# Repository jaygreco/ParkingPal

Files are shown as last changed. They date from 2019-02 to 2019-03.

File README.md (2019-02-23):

# ParkingPal
An open-source distance meter for easy garage parking. See [the thingiverse page](https://www.thingiverse.com/thing:3448336) for more info.

## How to use
Compile for the Arduino Pro Micro and upload. By default, the firmware is built for 8 LEDs (the NeoPixel Stick), and will poll the sensor at 3Hz until the read distance has been stable for roughly 10 seconds.

Single-pressing the button will change the operating mode. Double-clicking will cycle the brightness, and long-pressing will set the default parking distance. To set the default parking distance properly, park the car at the normal parking distance, and then long-press the button while making sure to stay clear of the ultrasonic sensor. Once set, the buzzer will beep once.

There are some configuration options in `config.h`. They should be pretty self-explanatory. There really isn't much need to change these unless you want to tweak some specific behavior. 

## Parts list
There's a more detailed BOM [here](https://github.com/jaygreco/ParkingPal/blob/master/PCB/0.1/MCU/MCU_BOM.xlsx).
### Required
| Qty | Part | Link |
|-----|---|---|
| 1 | Arduino Pro Micro | [SparkFun](https://www.sparkfun.com/products/12640) |
| 1 | NeoPixel Stick | [SparkFun](https://www.sparkfun.com/products/12661) |
| 1 | HC-SR04 Sensor | [SparkFun](https://www.sparkfun.com/products/13959) |
| 1 | SMT Pushbutton | [SparkFun](https://www.sparkfun.com/products/8720) |
| 1 | USB A Connector | [Digikey](https://www.digikey.com/products/en?keywords=380-1412-ND) |
| 1 | PCB - MCU | [OSHPark](https://oshpark.com/shared_projects/L5AVMKPm) |
| 1 | PCB - SMU | [OSHPark](https://oshpark.com/shared_projects/UerOD9Ji) |

### Optional (to include buzzer)
| Qty | Part | Link |
|-----|---|---|
| 1 | 12mm Buzzer | [SparkFun](https://www.sparkfun.com/products/7950) |
| 1 | 10k Resistor | [Digikey](https://www.digikey.com/products/en?keywords=RMCF0201FT10K0CT-ND) |
| 1 | 2N7002 N-Ch Fet | [Digikey](https://www.digikey.com/products/en?keywords=2N7002-TPMSCT-ND) |

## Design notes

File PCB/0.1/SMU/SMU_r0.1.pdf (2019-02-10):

USBPCB | USBPCB

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
J2 VCC

TRIG

ECHO USB | GND | USBSensor | USB

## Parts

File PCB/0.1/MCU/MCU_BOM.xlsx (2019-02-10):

Qty | Value | Part | Distributor | Package | Parts | Description
1 | 10k | RMCF0201FT10K0CT-ND | Digikey | 0603 | R1 | 0603 Resistor
1 | BUZZER-PTH_KIT | COM-07950 | Sparkfun | BUZZER-12MM-KIT | LS1 | 12mm Buzzer
1 | MOSFET-NCH-2N7002 | 2N7002-TPMSCT-ND | Digikey | SOT23-3 | Q1 | N-channel MOSFET
1 | SPARKFUN_PRO_MICRO_5V | DEV-12640 | Sparkfun | SPARKFUN_PRO_MICRO | B1 | SparkFun Pro Micro
1 | SWITCH-MOMENTARY-2SMD-REDUNDANT | COM-08720 | Sparkfun | TACTILE-SWITCH-SMD | S1 | NO SMT Button
1 | USB_A | 380-1412-ND | Digikey | USB-A-H | J1 | USB-A Connector

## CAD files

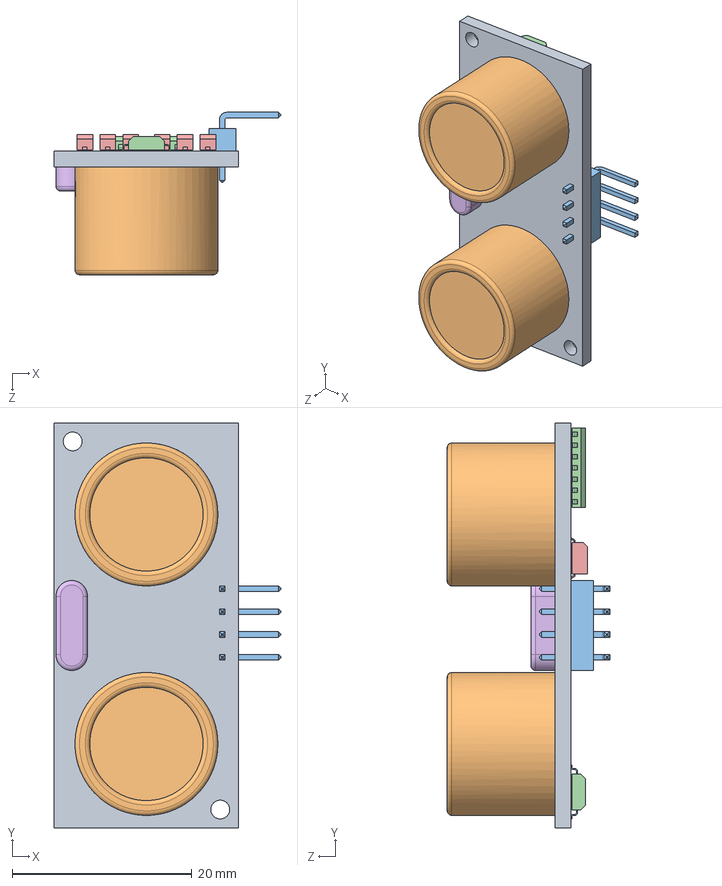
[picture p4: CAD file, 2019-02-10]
CAD/HC-SR04/HC-SR04 Ping Sensor.SLDASM
25.2 x 45.0 x 18.1 mm
PCB
Transducer x 2
3 Pin Header 90 Degree
14 Pin SMT x 3
Cap1 SMT x 6
HC-SR04 Crystal.SLDASM

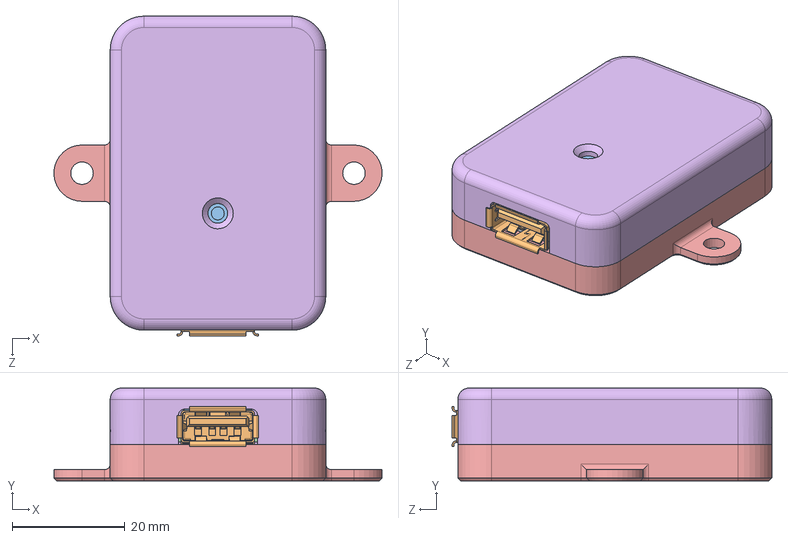
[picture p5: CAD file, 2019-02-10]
CAD/MCU_assem.SLDASM
58.2 x 16.5 x 56.8 mm
MCU_pcb
USB-A
Buzzer
ARDUINO PRO MICRO
Case_bottom
Case_top

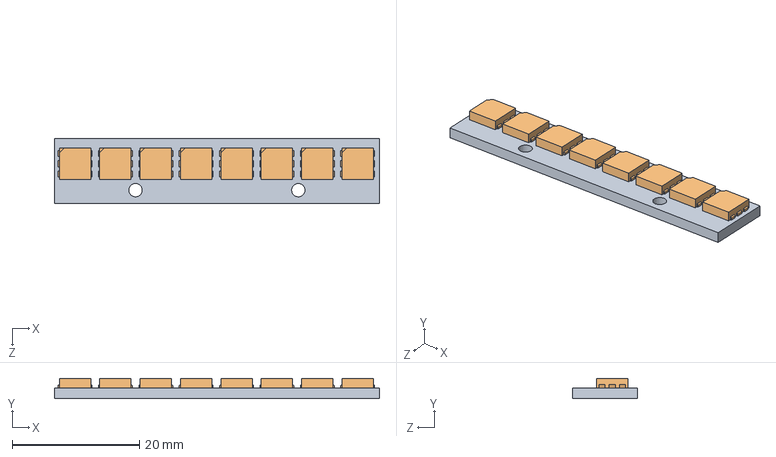
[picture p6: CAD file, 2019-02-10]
CAD/Neopixel Stick/NeoPixel Stick - 8 x WS2812 5050 RGB LED.SLDASM
51.1 x 3.19 x 10.2 mm
NeoPixel Stick - 8 x WS2812 5050 RGB LED
LED - SMD RGB (WS2812) x 8

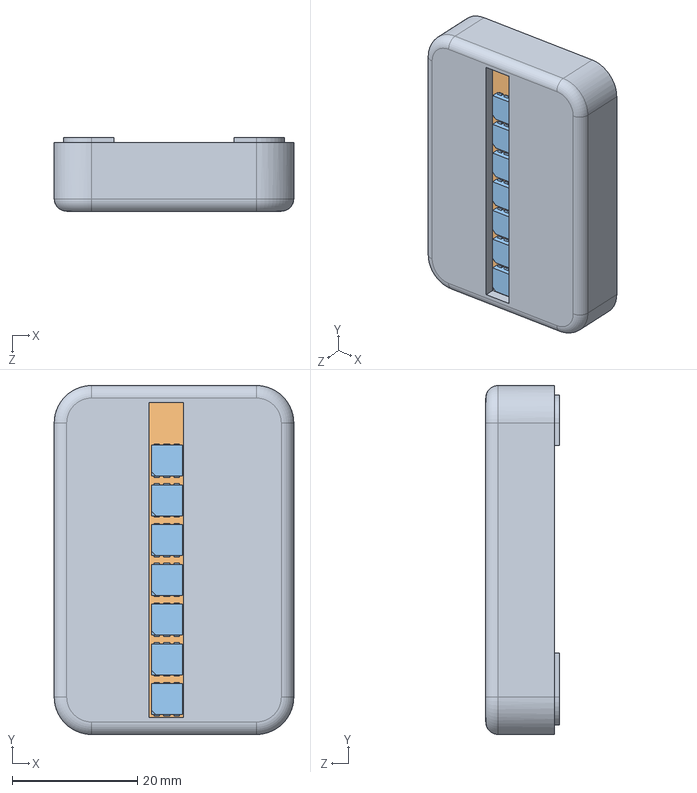
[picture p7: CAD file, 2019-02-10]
CAD/Neopixel Stick/Assem1.SLDASM
38.3 x 55.8 x 11.8 mm
Case_top
NeoPixel Stick - 8 x WS2812 5050 RGB LED
LED - SMD RGB (WS2812) x 7

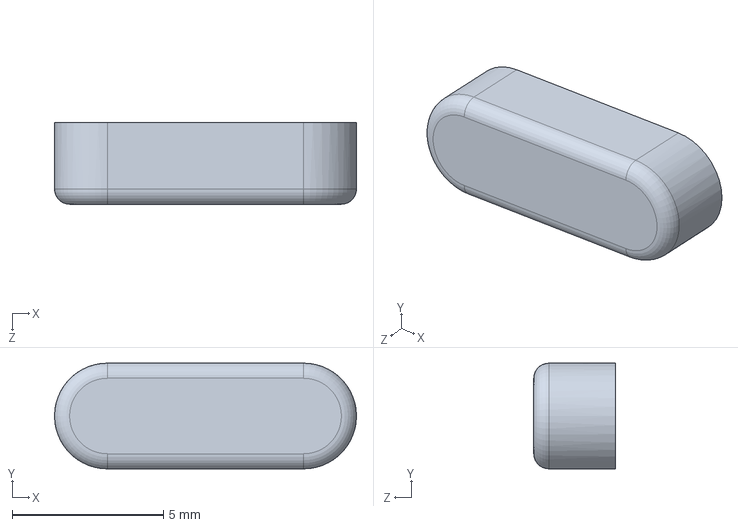
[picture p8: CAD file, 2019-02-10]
CAD/HC-SR04/HC-SR04 Crystal.SLDASM.SLDPRT
10.0 x 3.50 x 2.70 mm

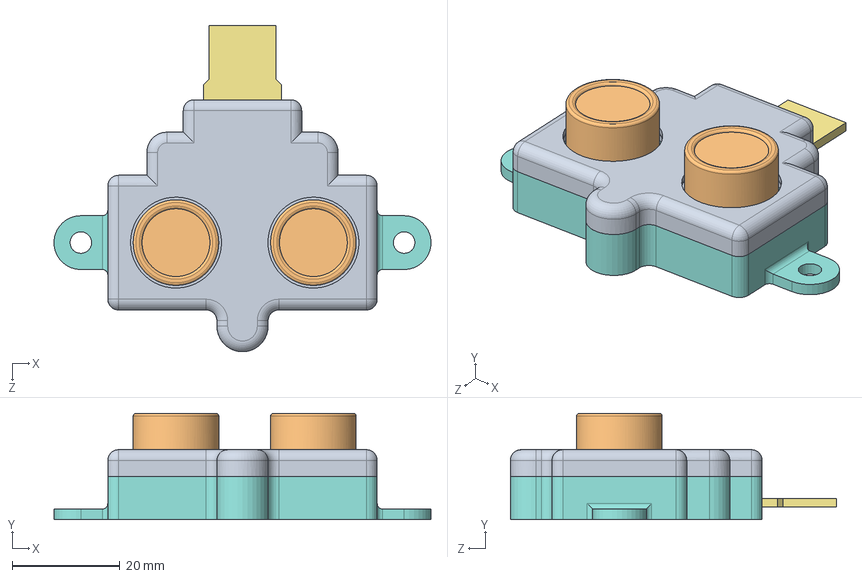
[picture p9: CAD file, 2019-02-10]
CAD/SMU_assem.SLDASM
70.0 x 19.8 x 60.6 mm
PCB
Transducer x 2
3 Pin Header 90 Degree
14 Pin SMT x 3
Cap1 SMT x 6
HC-SR04 Crystal.SLDASM
SMU_pcb
SMU_case_bottom
SMU_case_top

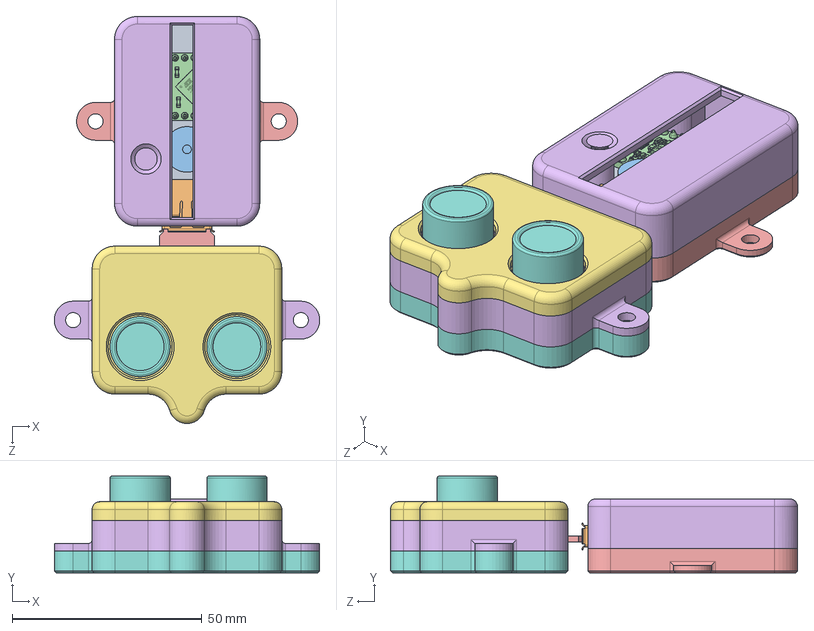
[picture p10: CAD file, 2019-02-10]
CAD/ParkingPal.SLDASM
70.0 x 25.5 x 107.3 mm
MCU_pcb
USB-A
Buzzer
ARDUINO PRO MICRO
Case_bottom
Case_top
PCB
Transducer x 2
3 Pin Header 90 Degree
14 Pin SMT x 3
Cap1 SMT x 6
HC-SR04 Crystal.SLDASM
SMU_pcb
SMU_case_bottom
SMU_case_top
SMU_spacer

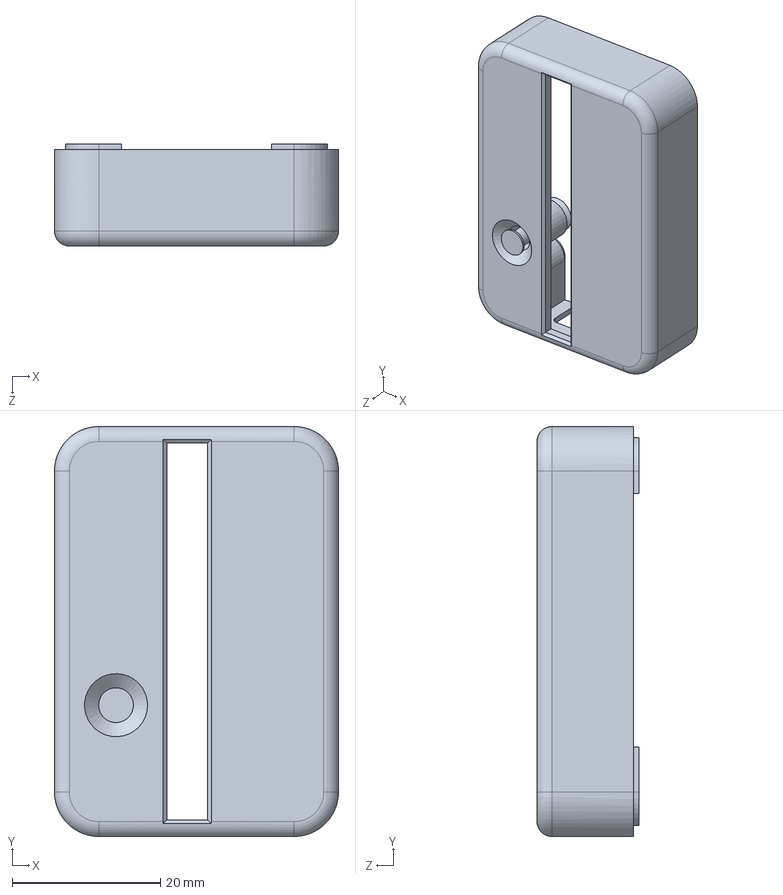
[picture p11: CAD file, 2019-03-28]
CAD/Case_top.SLDPRT
38.3 x 55.3 x 13.8 mm

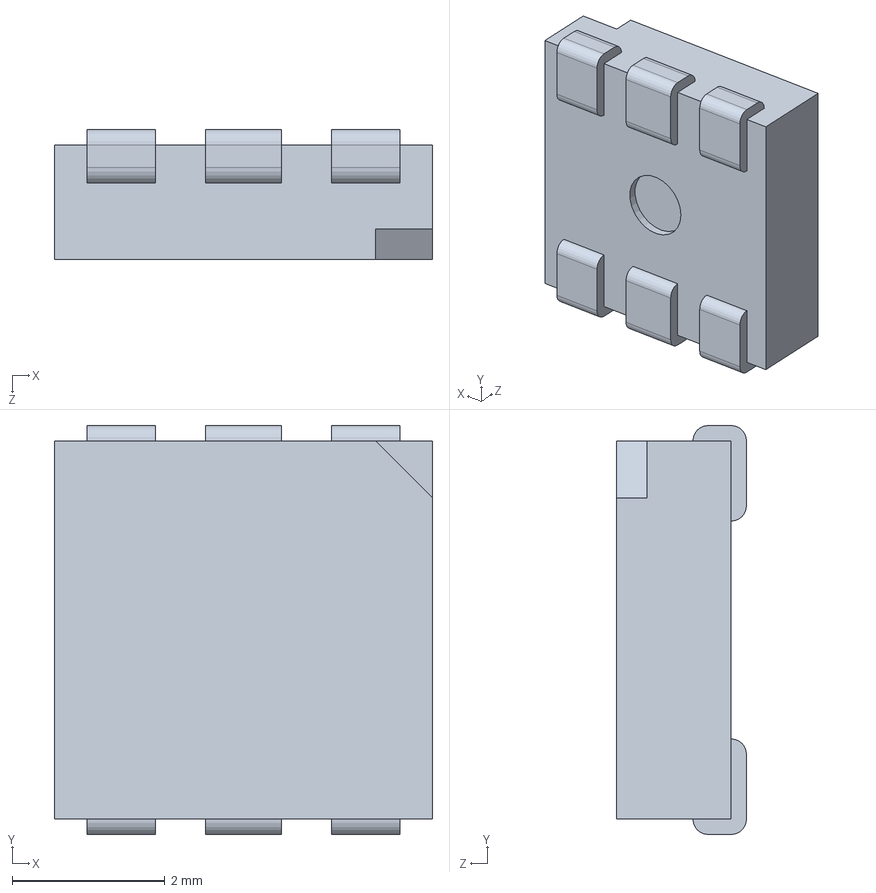
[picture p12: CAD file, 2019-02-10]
CAD/Neopixel Stick/LED - SMD RGB (WS2812).sldprt
4.95 x 5.35 x 1.70 mm

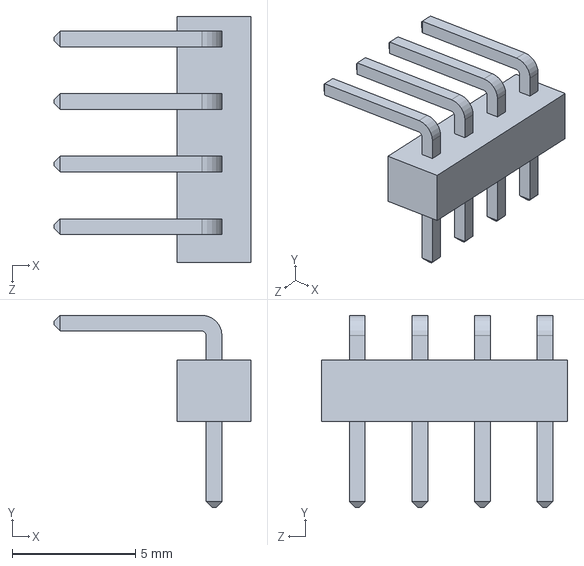
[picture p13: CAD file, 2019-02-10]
CAD/HC-SR04/3 Pin Header 90 Degree.SLDPRT
8.00 x 7.82 x 10.0 mm

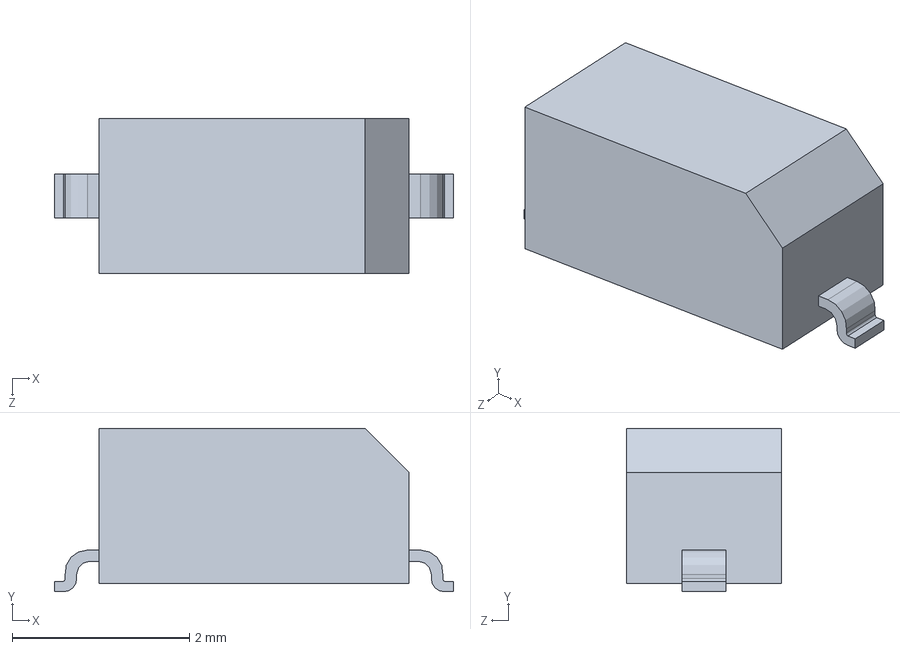
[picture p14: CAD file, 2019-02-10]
CAD/HC-SR04/Cap1 SMT.SLDPRT
4.50 x 1.84 x 1.75 mm

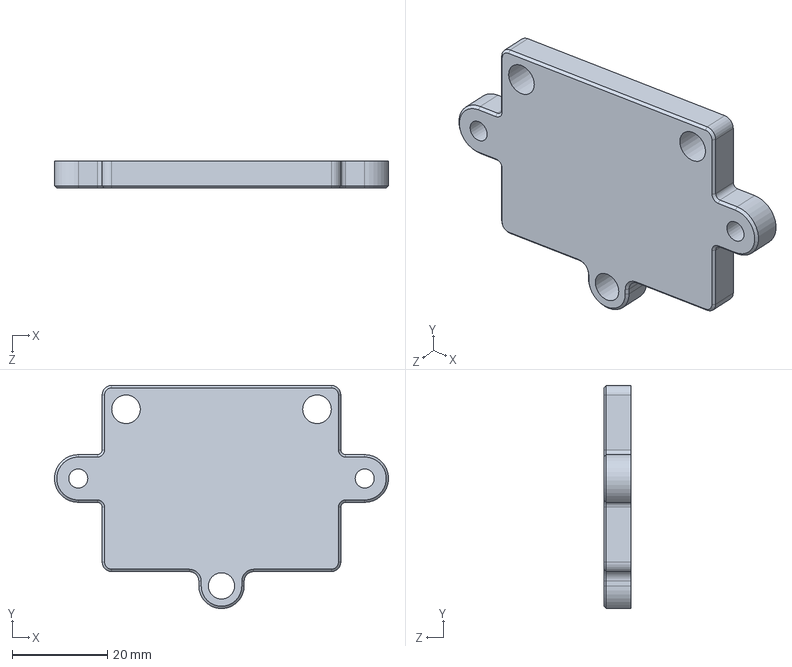
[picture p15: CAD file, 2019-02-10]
CAD/SMU_spacer.SLDPRT
70.0 x 46.8 x 5.75 mm

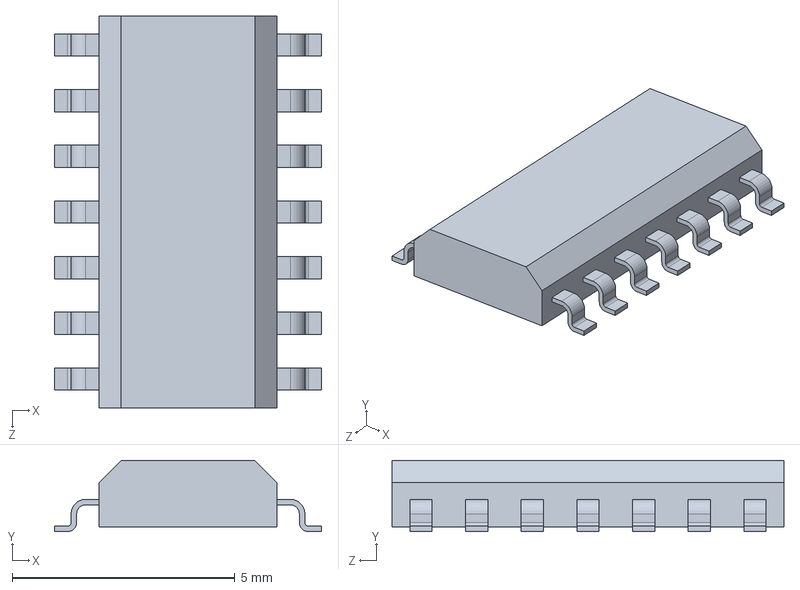
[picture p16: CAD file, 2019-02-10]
CAD/HC-SR04/14 Pin SMT.SLDPRT
6.00 x 1.60 x 8.80 mm

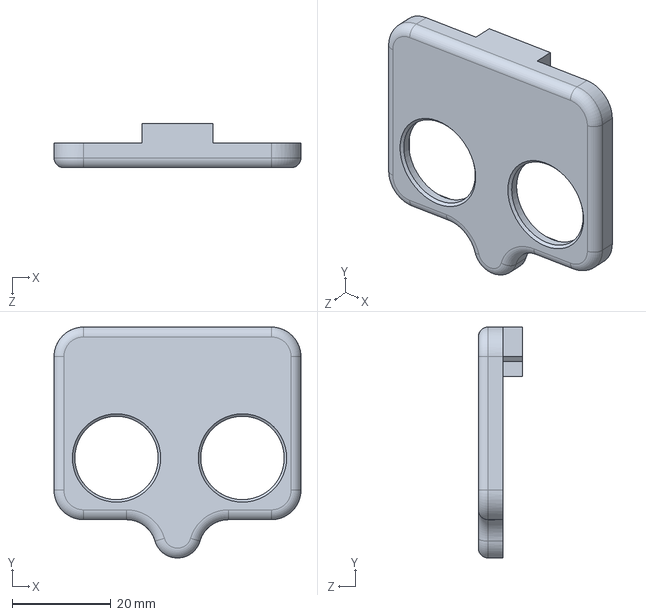
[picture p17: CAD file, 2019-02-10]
CAD/SMU_case_top.SLDPRT
50.0 x 46.7 x 9.00 mm

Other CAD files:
CAD/SMU_pcb.SLDPRT
CAD/HC-SR04/Transducer.SLDPRT
CAD/USB-A.SLDPRT
CAD/HC-SR04/PCB.SLDPRT
CAD/Buzzer.SLDPRT
CAD/Case_bottom.SLDPRT
CAD/MCU_pcb.SLDPRT
CAD/Neopixel Stick/NeoPixel Stick - 8 x WS2812 5050 RGB LED.SLDPRT
CAD/SMU_case_bottom.SLDPRT
CAD/hcSTP.SLDPRT

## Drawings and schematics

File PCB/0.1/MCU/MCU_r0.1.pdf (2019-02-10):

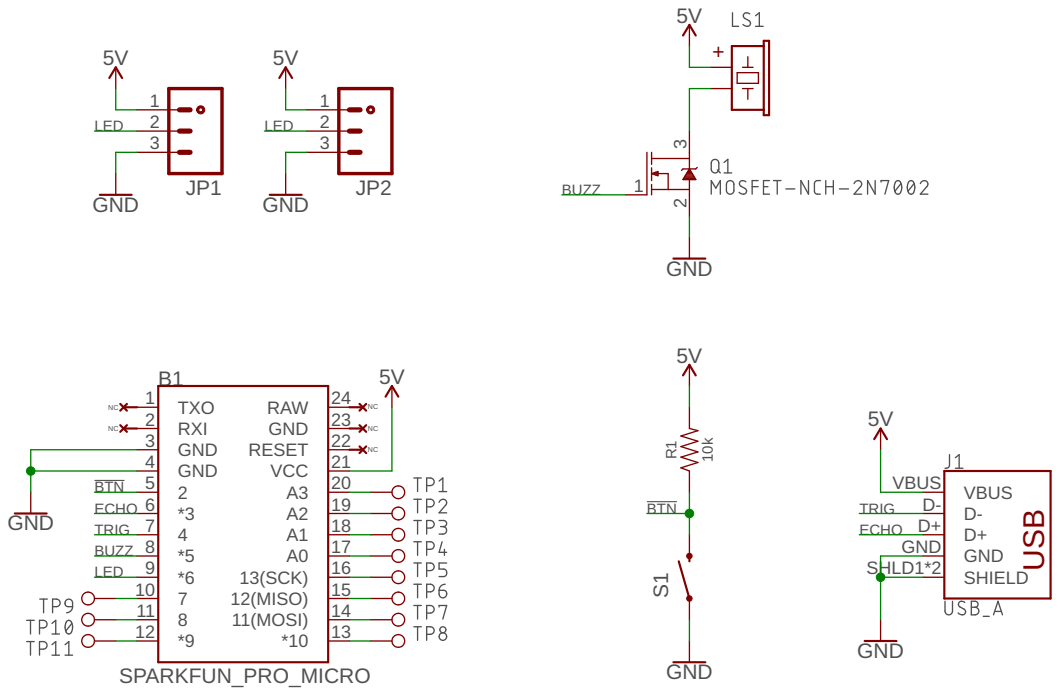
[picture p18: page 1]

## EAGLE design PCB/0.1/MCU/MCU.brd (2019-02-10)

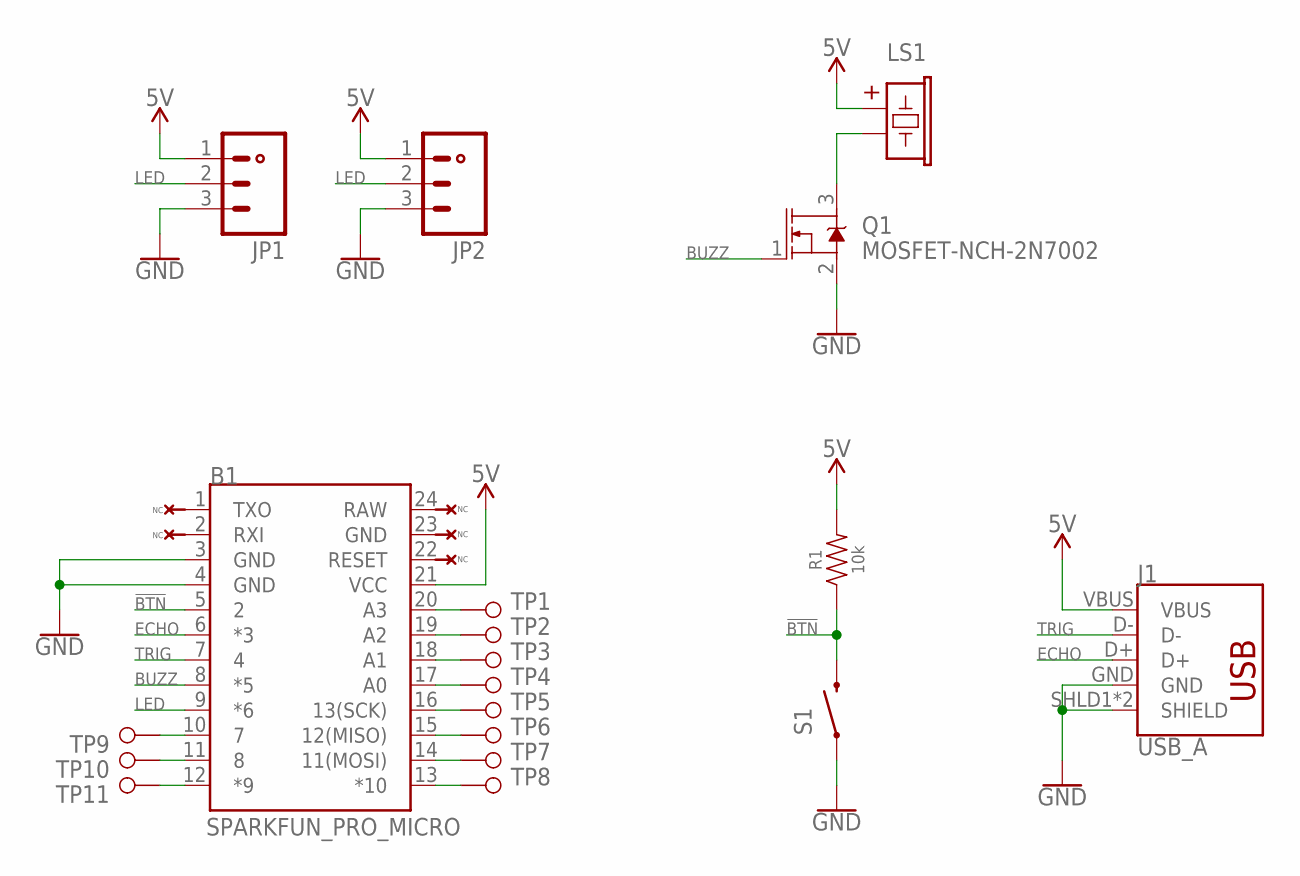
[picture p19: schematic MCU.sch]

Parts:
B1: SPARKFUN_PRO_MICRO
J1: USB_A; USB-A-H
JP1, JP2: M03PTH; 1X03
LS1: BUZZER-PTH_KIT; BUZZER-12MM-KIT
Q1: MOSFET-NCH-2N7002; SOT23-3
R1: 10k; 0603
S1: SWITCH-MOMENTARY-2SMD-REDUNDANT; TACTILE-SWITCH-SMD
TP1, TP2, TP3, TP4, TP5, TP6, TP7, TP8, TP9, TP10, TP11: TEST-POINT3X5; PAD.03X.05

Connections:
5V: B1.21 (VCC), J1.VBUS, JP1.1, JP2.1, LS1.+ (1), R1.2
!BTN: B1.5 (2), R1.1, S1.3 (2), S1.4 (2)
BUZZ: B1.8 (*5), Q1.1 (G)
ECHO: B1.6 (*3), J1.D+
GND: B1.3 (GND), B1.4 (GND), B1.23 (GND), J1.GND, J1.SHLD1 (SHIELD), J1.SHLD2 (SHIELD), JP1.3, JP2.3, Q1.2 (S), S1.1, S1.2 (1)
LED: B1.9 (*6), JP1.2, JP2.2
unnamed: B1.16 (13(SCK)), TP5.P$1
unnamed: B1.15 (12(MISO)), TP6.P$1
unnamed: B1.14 (11(MOSI)), TP7.P$1
unnamed: LS1.- (2), Q1.3 (D)
unnamed: B1.13 (*10), TP8.P$1
unnamed: B1.20 (A3), TP1.P$1
unnamed: B1.19 (A2), TP2.P$1
unnamed: B1.18 (A1), TP3.P$1
unnamed: B1.17 (A0), TP4.P$1
unnamed: B1.10 (7), TP9.P$1
unnamed: B1.11 (8), TP10.P$1
unnamed: B1.12 (*9), TP11.P$1
RAW: B1.24 (RAW)
TRIG: B1.7 (4), J1.D-

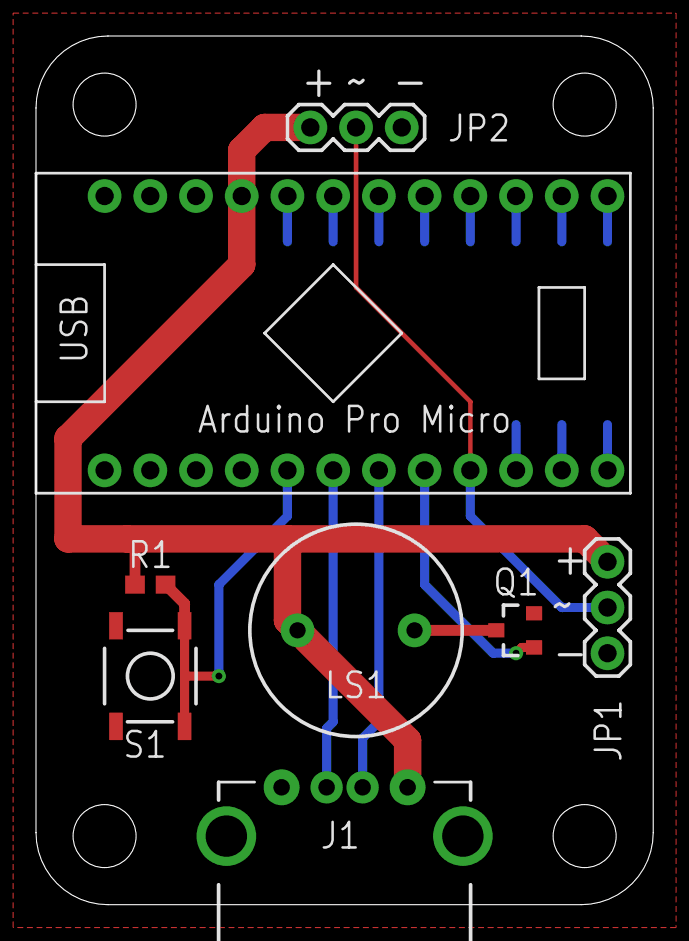
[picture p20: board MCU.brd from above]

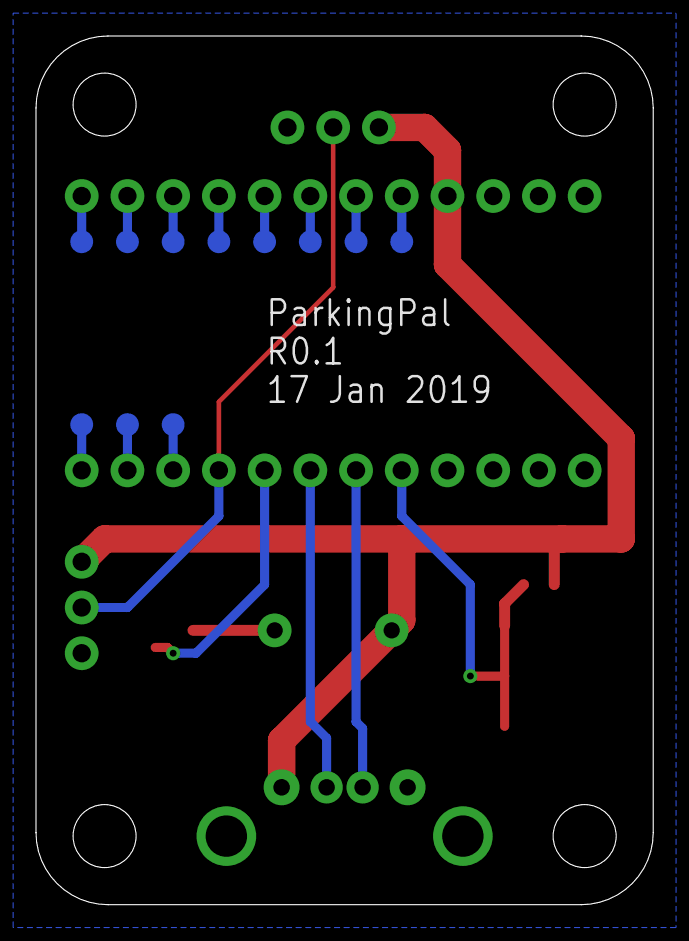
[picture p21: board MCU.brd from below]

Board: 2 copper layers, 34.3 x 48.3 mm, 19 parts (11 on the bottom side), 19 nets.

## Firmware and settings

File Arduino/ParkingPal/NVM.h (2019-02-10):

// Nonvolatile memory controls and functions.

#ifndef NVM_H
#define NVM_H

#include <Arduino.h>
#include <EEPROM.h>
#include "config.h"

#define EEPROM_MAGIC 0x01
#define DEFAULT_DIST_CM 80
#define DEFAULT_BRIGHTNESS 100
#define DEFAULT_LED_MODE 0
#define DEFAULT_BEEP_EN ((uint8_t) true)

enum offsets : uint8_t {
    MAGIC_NUMBER = 0,   // 1 byte
    PARKED_DIST_CM = 1, // 1 byte
    BRIGHTNESS = 2,     // 1 byte
    LED_MODE = 3,       // 1 byte
    BEEP_EN = 4         // 1 byte
};

class Eeprom {
public:
    Eeprom();

    void
    begin(void),
    setDefaultParkDist(uint8_t distance),
    setDefaultBrightness(uint8_t brightness),
    setDefaultLEDMode(uint8_t mode),
    printParams(void);

    uint8_t
    getDefaultParkDist(void),
    getDefaultBrightness(void),
    getDefaultLEDMode(void);

private:
    void
    configure(void),
    store(uint8_t offset, uint8_t data);

    uint8_t
    read(uint8_t offset);

    bool
    isConfigured(void);
};

#endif

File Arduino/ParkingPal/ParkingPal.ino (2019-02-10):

//#include <Adafruit_NeoPixel.h> //Uses AdafruitNeopixel: https://github.com/adafruit/Adafruit_NeoPixel
//#include <Ultrasonic.h> //Uses Ultrasonic: https://github.com/JRodrigoTech/Ultrasonic-HC-SR04
//#include <TimerThree.h> //Uses TimerThree: https://github.com/PaulStoffregen/TimerThree
#include <OneButton.h> //Uses Arduno_OneButton: https://github.com/mathertel/OneButton
#include <Narcoleptic.h> //Uses Narcoleptic library: https://github.com/brabl2/narcoleptic

#include "util.h"
#include "NVM.h"
#include "beeper.h"
#include "sensor.h"
#include "button.h"
#include "LED.h"

OneButton button(BTN_PIN, true);

void setup(void) {
    // Configure peripherals
    #if defined(DEBUG)
    Serial.begin(9600);
    delay(1000);
    #else
    TXLED1;
    delay(1000);
    RXLED1;
    #endif

    LEDs.begin();
    eeprom.begin();
    beeper.begin(BEEP_FREQ);

    // Disable things we don't need
    Narcoleptic.disableWire();
    Narcoleptic.disableSPI();
    ADCSRA &= ~(1<<ADEN); //Disable ADC
    ACSR = (1<<ACD); //Disable the analog comparator

    // Configure button handler
    button.attachClick(click);
    button.attachDoubleClick(doubleClick);
    button.attachLongPressStart(longPress);

    // Load defaults from EEPROM at startup
    sensor.setParkDistance(eeprom.getDefaultParkDist());
    LEDs.setParkDistance(eeprom.getDefaultParkDist());
    LEDs.setLEDBrightness(eeprom.getDefaultBrightness());
    LEDs.setMode(eeprom.getDefaultLEDMode());

    #if defined(PARAM_LOGGING) && defined(DEBUG)
    printParams();
    eeprom.printParams();
    #endif

    LEDs.flash(LED_FLASH_STARTUP);
}

void loop(void) {
    sensor.ping();
    button.tick();
    beeper.handle();

    #if defined(LOOP_LOGGING) && defined(DEBUG)
    // Loop logging statements go here
    // WARNING: This will absolutely blast the serial console if enabled
    #endif

    if (abs(sensor.distance() - sensor.average()) > DIST_THRESHOLD_CM) {
        // Active -- don't go to sleep.
        sensor.distance() <= sensor.parkDistance() ? beeper.enable() : beeper.disable();
        LEDs.setDistance(sensor.distance());
        LEDs.update();

    } else {
        if (!LEDs.fade()) {
            // Fading is done, we can go into sleep mode.
            #if USE_DEEP_SLEEP && !defined(DEBUG)
            Narcoleptic.delay(2*POLL_T_MS);
            #else
            #endif
        }
        beeper.disable();
    }
    delay(LOOP_DELAY);
}

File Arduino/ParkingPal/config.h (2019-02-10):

// ParkingPal defines and macros.

#ifndef CONFIG_H
#define CONFIG_H

// Hardware configuration
#define BTN_PIN 2
#define ECHO_PIN 3
#define TRIG_PIN 4
#define BUZZ_PIN 5
#define LED_PIN 6

// Beep configuration
#define BEEP_PERIOD_MS 500  // How long to beep for
#define BEEP_FREQ 2048      // Frequency to beep at
#define BEEP_DUTY_ON 50     // Buzzer duty cycle when on (percent)
#define BEEP_DUTY_OFF 0     // Buzzer duty cycle when off
#define BEEP_DUTY_SFX 10    // Duty cycle for sound effects (percent)

//Sensor configuration
#define PING_TIMEOUT 25000      // Sets maximum sensor distance
#define WINDOW_FILTER_TIME_S 10 // Window filter length in seconds
#define POLL_FREQ 3             // How frequently to poll the sensor
#define POLL_T_MS (1.0/POLL_FREQ)*1000
#define NUM_SEN_SAMPLES POLL_FREQ * WINDOW_FILTER_TIME_S
#define NUM_DIST_SAMPLES 3      // Distance window filter 

// LED configuration
#define FLIP_LEDS true		// Flip LED orientation
#define NUM_LEDS 8          // Number of LEDs in your light setup
#define MAX_LED_MODES 4     // Number of LED modes to switch through
#define BRIGHTNESS_MIN 50   // Lowest brightness setting
#define BRIGHTNESS_MAX 250  // Maximum allowable brightness of LEDs
#define BRIGHTNESS_INC 50   // Amount to increment brightness by
#define LED_FADE_MS 3000    // How long to fade out LEDs when going idle

// LED modes
#define LED_MODE_BAR 0
#define LED_MODE_RG 1
#define LED_MODE_RYG 2
#define LED_MODE_STOPLIGHT 3
#define LED_FLASH_WAVE 0
#define LED_FLASH_BLUE 1
#define LED_FLASH_STARTUP 2
#define LED_FLASH_MODE 3

// System configuration
#define DIST_THRESHOLD_CM 5     // Don't wake unless distance has changed this much
#define DISTANCE_MAX_CM 350     // Maximum distance to measure
#define SAFE_ZONE_CM 20         // Safe zone buffer ahead of beeping
#define LOOP_DELAY 50           // How frequently to poll the loop
#define USE_DEEP_SLEEP false     // Sleep using low power library

// Debug settings
//#define DEBUG
#define PARAM_LOGGING
#define LED_LOGGING
#define LOOP_LOGGING
#define EEPROM_LOGGING
#define PING_LOGGING
#define BUTTON_LOGGING

#endif
